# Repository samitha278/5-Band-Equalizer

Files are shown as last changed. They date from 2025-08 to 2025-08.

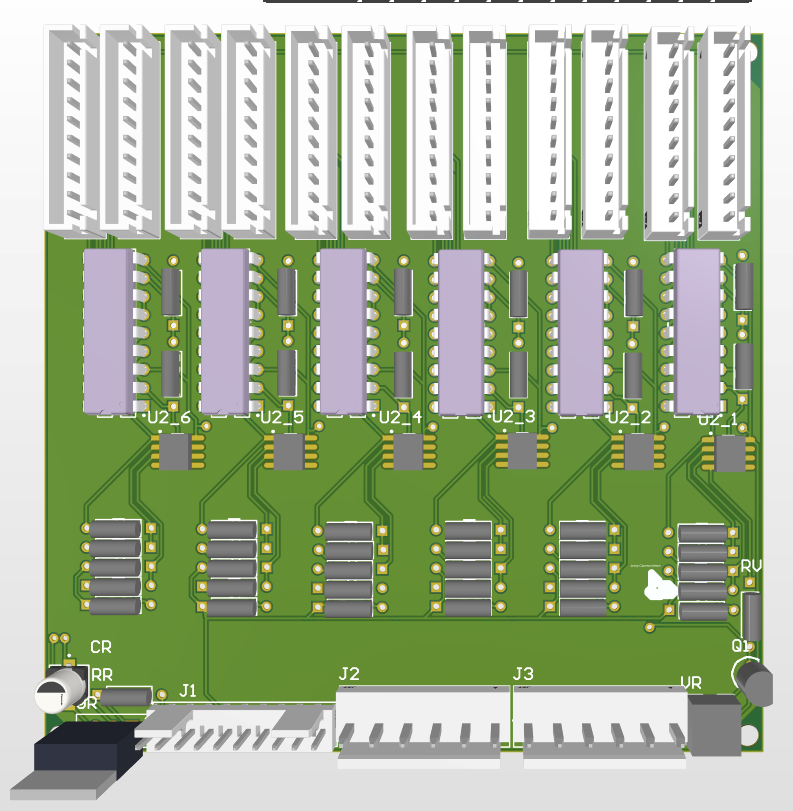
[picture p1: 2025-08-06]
Images/Design and Schematics/display.png

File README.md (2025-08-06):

# 🎚️ 5-Band Analog Audio Equalizer - Hertz Labs

A robust, fully analog 5-band audio equalizer designed and built by undergraduate students of the Department of Electronic and Telecommunication Engineering, University of Moratuwa. The project features selective gain control across five standard audio frequency bands, with a real-time LED bar display for audio levels — all using only fundamental analog components like op-amps, resistors, capacitors, and transistors.

> 📡 Designed for: EN2091 Laboratory Practice and Projects  
> 🧪 Built by: Team Hertz Labs  
> 🎓 University of Moratuwa

---

## 📷 Project Overview

This 5-band equalizer allows users to independently adjust the gain across the following audio frequency bands:

- **20 Hz – 300 Hz** (Sub-bass)
- **300 Hz – 1 kHz** (Bass/Mid)
- **1 kHz – 4 kHz** (Midrange)
- **4 kHz – 10 kHz** (Upper midrange)
- **10 kHz – 20 kHz** (Treble)

The design ensures minimal distortion when idle, accurate band separation, and robust gain control without digital processing — preserving the integrity of the original analog signal.

---

## 🧩 System Architecture

The system is divided into two main blocks:

### 1. 🎛️ Filter & Control Section
- **Input/Buffer Stage:** Inverting amplifier with a gain of -2 and DC shift to mid-voltage.
- **Filter Bank:** Five fourth-order bandpass filters, each built using two cascaded Sallen-Key second-order filters.
- **Adder Stage:** Inverting summing amplifier that combines the filtered signals, each weighted by a volume potentiometer.
- **Mid-Voltage Generator:** Provides a virtual ground reference for single-supply operation.

### 2. 💡 Display Section
- **Differential Amplifiers:** Monitor current flow to the adder circuit without affecting audio fidelity.
- **LED Display Driver:** LM3914 IC used to drive 10-segment LED bar graphs for each frequency band.

---

## 🧠 Key Design Choices

- **Single-Supply Design:** Operates at 18V with mid-voltage reference, avoiding complex dual supply requirements.
- **High-Order Filters:** Fourth-order filtering for each band ensures steep roll-off and minimal overlap.
- **Current-Limiting Resistors:** Prevents saturation at the adder stage and ensures smooth audio performance.
- **Component Compactness:** Utilized SMD op-amps (TL072) for filters and through-hole components where needed for durability and signal integrity.

---

## 📐 Hardware and PCB

- **Design Software:** Altium Designer (2-layer PCB)
- **Main PCB Size:** 100 mm × 84 mm
- **Display PCB Size:** 100 mm × 100 mm
- **Enclosure:** Custom-designed with SolidWorks. PLA+ 3D printed main body + laser-cut plywood front panel.
- **Inputs/Outputs:** 3.5 mm audio jacks and barrel jack for power input.

---

## 🔬 Simulation & Testing

- **Simulation Software:** LTSpice
- **Verification:** Individual filter responses and system-level flat gain tested in simulation.
- **Prototyping:** Breadboard implementation before final PCB.
- **Final Testing:** Oscilloscope and audio output testing verified each band’s control and system integrity.

---

## 🛠️ Components Used

| Component | Description |
|---|---|
| TL072 Op-Amp | Low noise, low distortion, wide bandwidth — ideal for audio applications.  |
| LM3914 | Bar graph LED driver with linear scale, built-in reference voltage. |
| Potentiometers | Sliding potentiometers used for precise gain control of each band. |
| Passive Parts  | Standard 0.25W resistors, film capacitors selected for precision and stability. |

---

## 🚧 Future Improvements

- 🔋 **Custom Power Supply**: Develop an in-house 18V power supply for standalone operation.
- 💡 **Display Enhancement**: Refine LED driver circuit for more accurate real-time response.
- 🔊 **More Bands**: Extend to a 7-band or 10-band equalizer for finer audio tuning.

---

## 👥 Team Members

-Jayakody J.A.K
-Pelagewatta H.P
-Jayarathne H.A.C.N
-Bandara M.A.G.S

---

## 🔗 References

- [LM3914 Datasheet](https://www.ti.com/lit/ds/symlink/lm3914.pdf)
- [Sallen-Key Filter Design Guide - TI](https://www.ti.com/lit/pdf/sloa096)
- [Medium Blog Inspiration](https://medium.com/@vgr0876/5-band-audio-equalizer-8df9b991d8ea)

---

## 📂 Repository Structure

```bash
5-Band-Equalizer-HertzLabs/
├── Schematics/           # LTSpice and Altium design files
├── PCB_Design/           # PCB layout files (Main + Display)
├── Enclosure/            # SolidWorks and Laser-cut designs
├── Media/                # Photos and demo videos
├── Report/               # Final PDF report and documentation
└── README.md             # This file

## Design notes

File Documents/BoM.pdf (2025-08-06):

## Bill of Materials

Component | Quantity | Unit Price (Rs) | Price (Rs)
TL072CP OpAmp SMD | 12 | 80 | 960
LM3914 | 6 | 100 | 600
PCBs | 1 | 6500 | 6500
Enclosure | 1 | 5400 | 5400
Resistor Cards | 2 | 380 | 760
Capacitors | | | 500
Sliding Potentiometer | 6 | 240 | 1440
Barrel jack | 1 | 45 | 45
6.5mm Audio Connector | 2 | 270 | 540
Switch | 1 | 30 | 30
LED Bar graph | 6 | 140 | 840
| | Total | 17615

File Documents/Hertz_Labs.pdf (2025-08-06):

5 Band Equalizer | Hertz Labs
EN2091

# Laboratory Practice and Projects

# 5-Band Equalizer

# Team – Hertz Labs

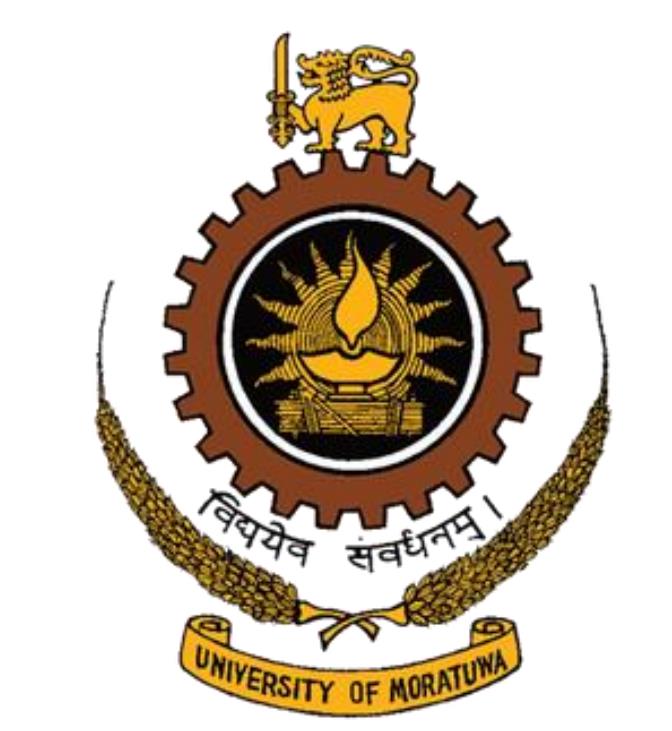
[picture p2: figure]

Electronics and Telecommunications Department,

## University of Moratuwa

Members
220247J | Jayakody J.A.K
220455U | Pelagewatta H.P
220252U | Jayarathne H.A.C.N
220064U | Bandara M.A.G.S.

## Abstract

This report contains an overview of the design of a 5-band equalizer based on basic electronic components such as OP AMPs, resistors, capacitors and transistors. The Equalizer is designed to work for an input voltage range of 18-30V and provides highly selective individual band gain adjustment with minimal distortion to the other band responses. The equalizer at rest position

introduces minimal distortion to the response.

### The fundamental building blocks of the equipment and the core concepts related to it, simulation methodologies, testing methods, components

selection, PCB design and enclosure design is briefly discussed in the report.

### The final output and audio testing has given very pleasing results with accurate gain adjustments both in audio outputs and oscilloscope measurements

proving the effectiveness of the design.

## Content

Introduction | 4
Functionality | 4
System Architecture, Major Design Decisions and Fulfilling the Given Requirements | 4
Component Selection | 9
PCB Design | 10
Enclosure Design | 11
Software Simulation | 12
Practical Implementation and Testing | 12
Conclusion | 13
Future Work | 13
Individual Contribution | 13

### References

13

## Introduction

### An audio equalizer can adjust the output of different frequency bands individually based on a given audio signal. The project was centred around making an equalizer with gain control of 5 individual bands using only basic analog electronic equipment. The audio levels of each band must be

graphically indicated using a sound level indicator.

## Functionality

The input/ buffer receives the audio signals and add a DC shift to bring the signal to the mid voltage.5 band pass filters tuned to the assigned bands decompose the input audio signals. These filtered signals are added by an adder circuit and the proportions of adding are controlled by volume controllers. (potentiometers). The Output is driven by the same Adder output.

The frequency ranges of each band.

– 20-300 Hz
– 300 - 1 kHz
– 1kHz - 4 kHz
– 4kHz - 10kHz
– 10kHz - 20kHz

## System Architecture, Major Design Decisions and Fulfilling the Given Requirements

The design decision was taken to go for a single supply design since we are expecting to rely on a external power supply with normally provides a single supply. (External dual power supplies are rare in market)

So, all the stages of the circuit was designed to work according to it.

### Block Diagram

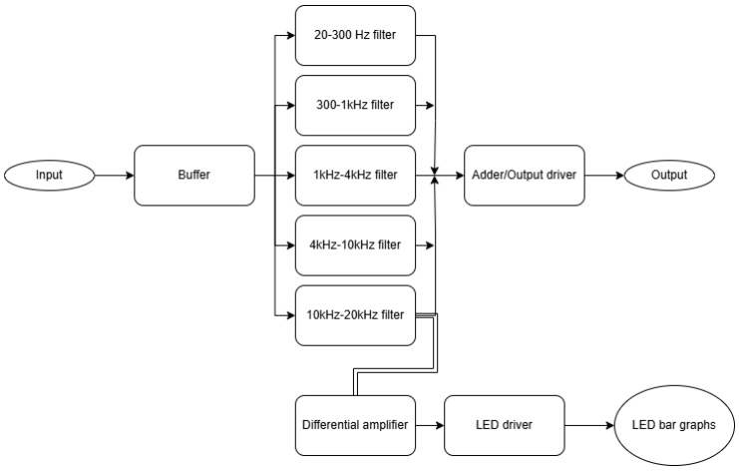
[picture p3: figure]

Figure 1-Functional block Diagram

The system is divided into 2 major parts.

1. Filter section
2. Display control section

Filter section

Consists of 3 stages
1. Input/Buffer stage – A inverting amplifier of gain -2
2. Filter stage - 2 second order Sallen key multiple feedback bandpass filters cascaded to get a fourth order filter for each band. 5 such filters are present.
3. Adder/Output stage – Volume controllers are used to control the contribution from each band and the current is passed through the adder circuit to generate the output voltage.

Additionally, it has a mid-voltage generator section- Mid voltage is taken to act as the virtual ground to simplify the design the single supply op amp circuits.

Display Section

Consists of 2 stages

1. Differential amplifier stage – Sense the current levels of each filter stage flowing to the adder section without introducing distortion to the bands
2. LED driver stage – Drive a 10 LED bar graph display proportional to the voltage output of the first stage.

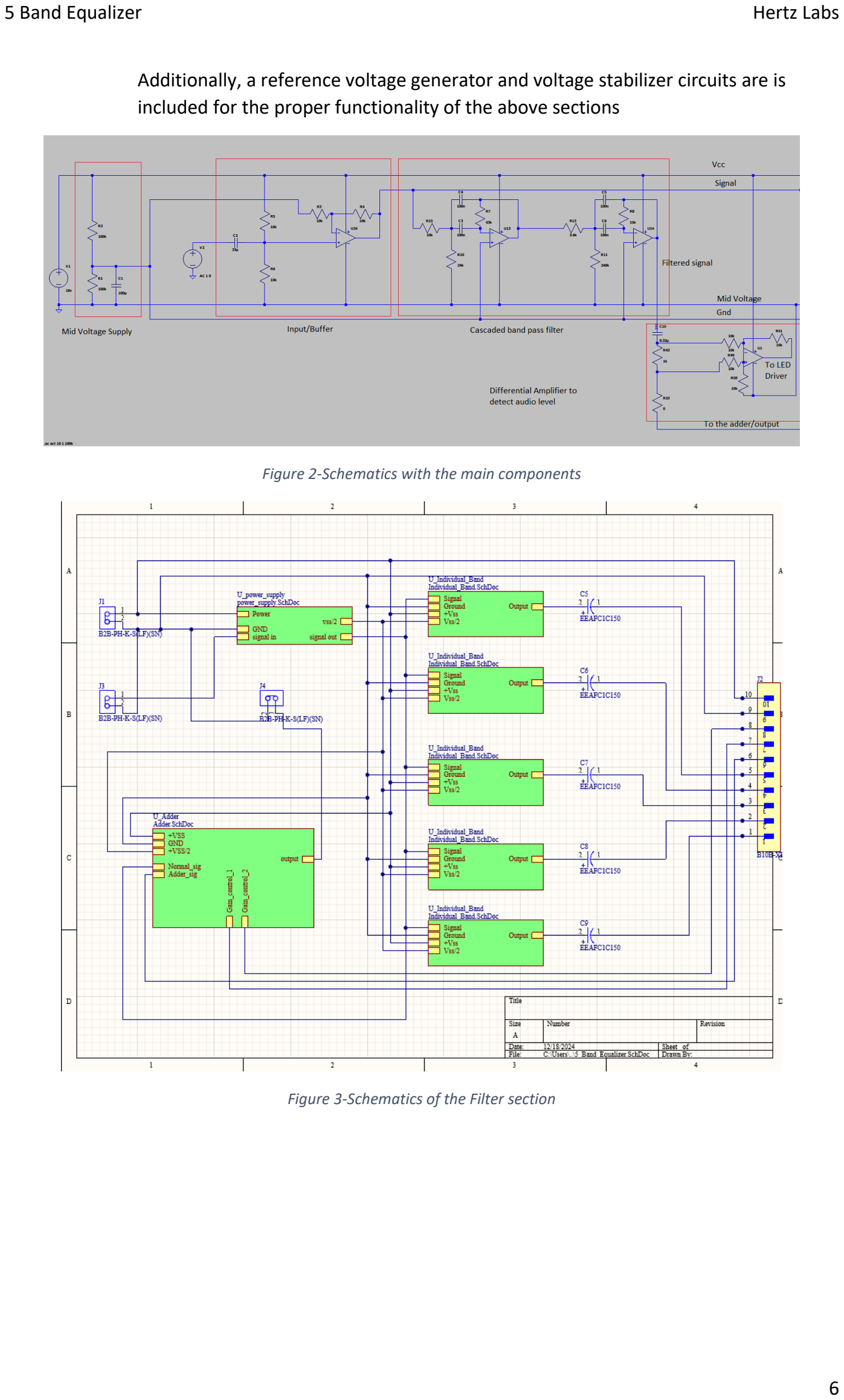
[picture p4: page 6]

Additionally, a reference voltage generator and voltage stabilizer circuits are is included for the proper functionality of the above sections

Figure 2-Schematics with the main components

Figure 3-Schematics of the Filter section

### Use of analog electronics for implementation (transistors and operational amplifiers)

- Input/stage

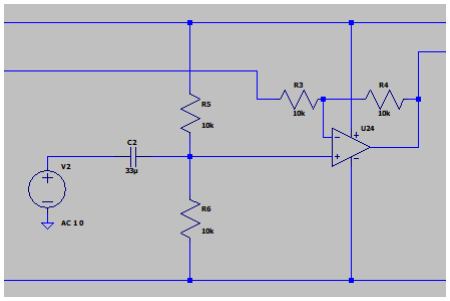
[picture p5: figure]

The input stage is an inverting amplifier constructed using a single OP amp and resistors. This stage introduces a DC shift to the signal and give a gain of -2. The gain is introduced to manipulate the signals with minimal
introduction of noise from the filters and background noise. The input stage has an almost flat frequency response (High pass)
- Filters

The filter stages is
constructed by cascading 2 Sallen key multiple feedback band pass filters to get a fourth order filter. This is used to give a steep roll off which gives a good selectivity. Also, the filters are tuned such that the first filter is handling the first portion of the filter while the second filter handles the
second portion of the

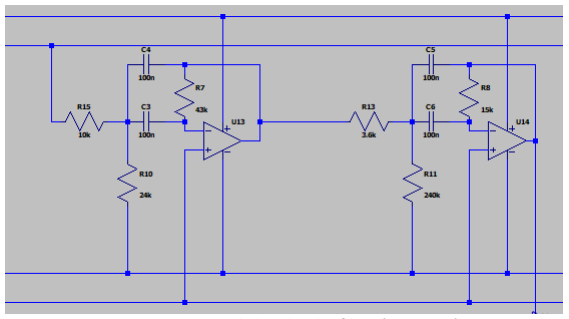
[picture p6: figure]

band. This ensure that the pass band has a flat mid frequency gain.

Adder stage

Adder is an OP amp based single supply adder circuit which combines the signals from the filters proportional to the resistance introduced by the volume controllers between the filter and the adder. The adder circuit is also inverting the signal which ultimately converts the signal to the original phase.

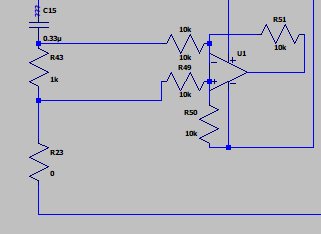
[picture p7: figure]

Differential amplifier

The differential amplifier is connected to the saturation control resistor. The differential amplifier senses the voltage difference between the resistor which is proportional to the current flow through it. Then it outputs the output which is in the range of the input

Figure 4-Input Stage

Figure 5- cascaded 2nd order filters(4th order)

signals to the display driver. Due to the high input impedance of the differential input this does not introduce any distortions to the signal.

Display driver.

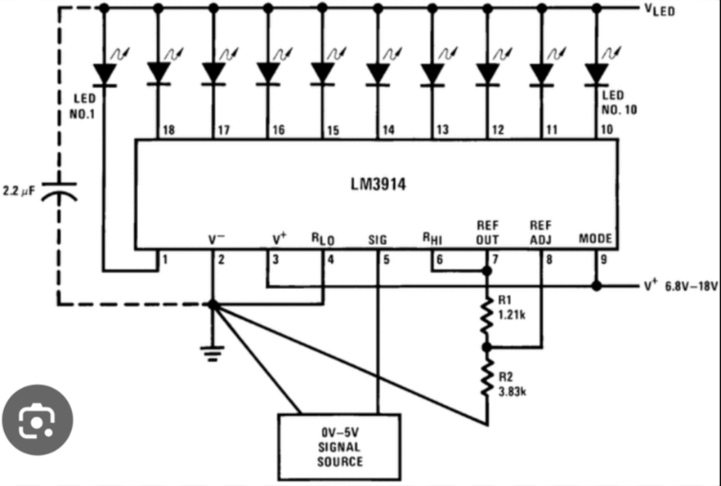
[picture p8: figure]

We have used a 10 segment display driver(LM3914) which switches the LEDs proportional to the input voltage ranging from 0-5V

Capable of adjusting the gain individually across 5 frequency bands.

As described previously this requirement is achieved by filtering the signal into several bands and then controlling the contribution of each band to the final output individually.
Mechanisms to avoid signal saturation.

A current control resistor is introduced between the filters and the volume controllers which limits the current to the adder stage. This ensures that the final output stage will not be saturated by any means. The value of this resistor is calculated such that for any position of the volume controller the input current to the adder circuit is controlled and the output is not saturated. Furthermore, all the filters are designed to handle input voltage variations way beyond the normal audio line voltages. This ensures that for any normal audio signal, the input/buffer stage and the filter stages will not saturate. The supply voltage of the system was selected to be 18V which was decided on the fact that 12V supply voltage is the minimum voltage needed to avoid saturation of the signals.

## Component Selection

Op amp selection – We decided to use TL 072 OP amp for all the circuits in the system.

### The TL072 operational amplifier (op-amp) is often considered good for audio applications due to several characteristics that make it well-suited for this purpose:

### 1. Low Noise: The TL072 has low noise characteristics, which are crucial in audio applications where signal fidelity is important. Low noise helps in maintaining the

quality of the audio signal being amplified.

### 2. High Input Impedance: The TL072 has a high input impedance, which means it won't load down the preceding stages in an audio circuit. This is important to prevent signal

loss and distortion.

### 3. Wide Bandwidth: The TL072 has a wide bandwidth, making it suitable for audio

applications where a broad frequency range needs to be amplified without distortion.

### 4. Low Distortion: The TL072 has low distortion characteristics, which are essential for

maintaining the fidelity of audio signals as they pass through the amplifiers and filters.

### 5. Dual Op-Amp Configuration: The TL072 is a dual op-amp in a single package, which is

convenient for filter stages since each stage needs 2 OP amps.

### 6. Ease of Use and supply: It is a commonly used and well-documented op-amp, making it easier for designers to find information, application notes, and example circuits for

audio applications.

### We used SMD Op amps for all the filters and the adder to increase the compactness of the PCB and we used a Through hole Op amp since this has to introduce a DC sift for the signal

Resistors - All the resistors were selected based on the calculations needed for filters and the other circuits. All the resistors are 0.25W resistors since all the circuits deal with signals. The resistor selection for the op amp circuits were done such that they fall in the range of 1kohm to 100kohm to avoid injection of thermal noises to the signals.

### Display driver – LM3914

### 1. Bar/Dot Display Modes: The LM3914 can operate in either bar mode or dot mode, allowing flexibility in how the display is presented based on the application requirements. We decided to use the bar mode 2. Linear Voltage Scale: The LM3914 has a linear voltage scale, which is useful for

applications where a linear representation of levels or quantities is needed, such as audio level indicators which is exactly our requirement.

### 3. Wide Voltage Range: The LM3914 can operate over a wide range of supply voltages, making it versatile and suitable for various power supply configurations. This makes the use of a separate supply circuit to the display

drivers unnecessary.

### 4. Internal Voltage Reference: The LM3914 includes an internal voltage reference, simplifying the design by eliminating the need for an external voltage reference. This gives our device the ability to work on defferent supply voltages

while still maintaining a fixed scale.

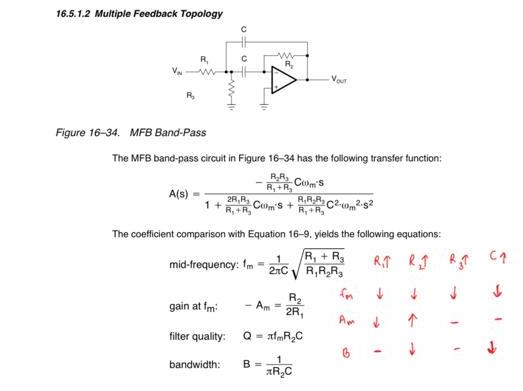
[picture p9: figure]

## PCB Design

The printed circuit board (PCB) for the 5-Band Audio Equalizer was designed using Altium Designer with 100 mm × 84 mm dimensions. The design utilizes a two-layer PCB architecture to accommodate the circuit complexity while maintaining an organized layout.

The PCB was fabricated in China and shipped to Sri Lanka for assembly and testing. The trace width for signal lines is 0.254 mm, ensuring optimal current flow and signal integrity. The drill hole diameter for PCB mounting is 3 mm, providing adequate mechanical support and alignment.

The placement of components was carried out systematically to ensure clarity and ease of understanding. Each frequency band is distinctly organized, enabling intuitive identification and streamlined troubleshooting. This structured layout enhances both the functionality and usability of the PCB, facilitating efficient assembly and testing processes.

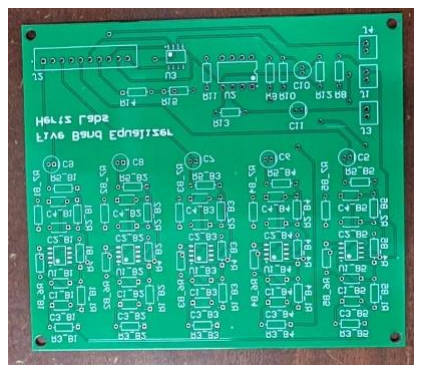
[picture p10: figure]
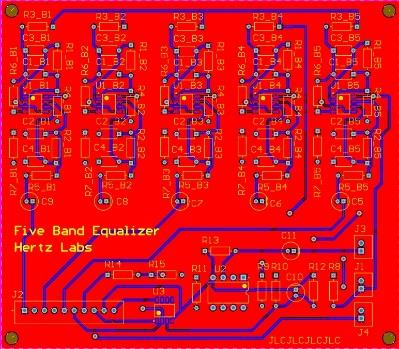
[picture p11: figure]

In addition to the main PCB, a separate display PCB was designed for the 5-Band Audio Equalizer using Altium Designer. This PCB measures 100 mm × 100 mm and features a two-layer design to support the display components.

The trace width for signal lines is 0.254mm, ensuring reliable electrical connections, while the drill hole diameter is maintained at 3 mm for PCB mounting.

The components on the display PCB, such as the LED bar graph displays and sliding potentiometers, are strategically organized to align precisely with the corresponding features of the enclosure. This alignment ensures seamless integration of the display interface with the enclosure design, resulting in a user-friendly and visually coherent system layout.

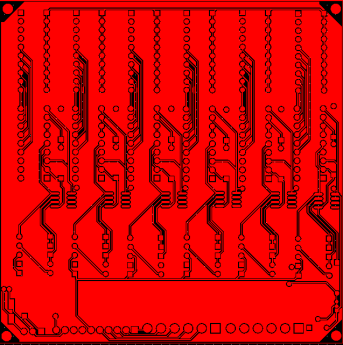
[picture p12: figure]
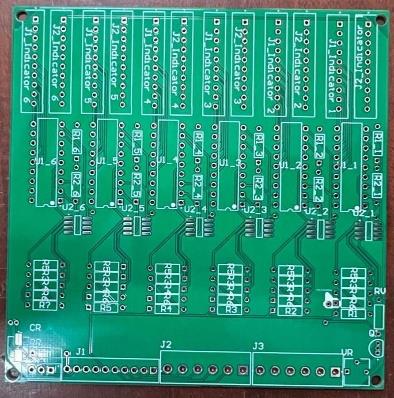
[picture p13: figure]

## Enclosure Design

The enclosure for the 5-Band Audio Equalizer was designed using SolidWorks and consists of three distinct components: the Main Container, the Lid, and the Face. The enclosure dimensions are 150 mm × 142 mm, ensuring compactness while accommodating all required components.

- The Main Container and Lid were fabricated using 3D printing technology with PLA+ filament for enhanced durability and precision.
- The Face of the enclosure was laser-cut from a plywood sheet, providing a robust and aesthetically appealing front panel.

The enclosure integrates the following components:

- 5 sliding potentiometers for adjustable gain control.
- 5 LED bar graph displays for real-time visual feedback.
- 1 switch for system control.
- 2 audio jack connectors (65 mm) for audio input and output.
- 1 barrel jack connector for power supply.

The main PCB is mounted on the inner face of the lid, while the display PCB is securely mounted inside the Main Container. Both PCBs are positioned in a face-to-face configuration, simplifying wire connections and minimizing signal interference, ensuring efficient assembly and reliable operation.

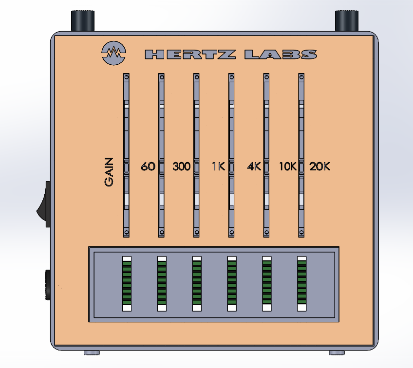
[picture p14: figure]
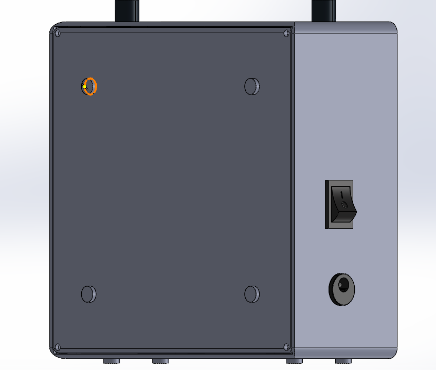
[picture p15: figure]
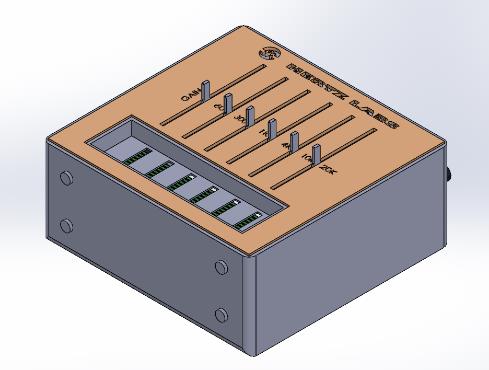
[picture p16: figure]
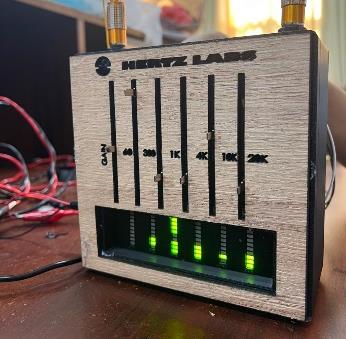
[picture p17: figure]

## Software Simulation

The circuit was simulated using LTSpice software to verify its performance and optimize component values. The output response for each frequency band was plotted, demonstrating accurate results with a well-defined roll-off at the frequency edges. Based on the simulation results, appropriate resistor and capacitor values were carefully selected to ensure precise frequency band separation and optimal performance of the 5-Band Audio Equalizer.

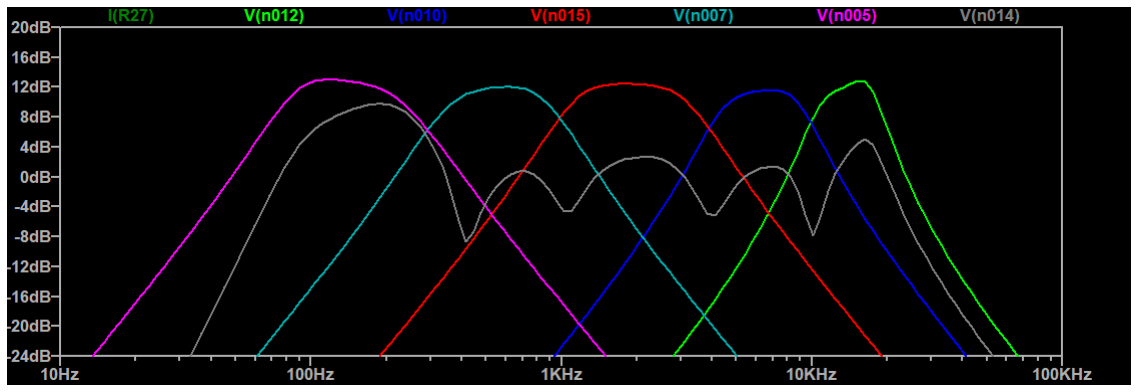
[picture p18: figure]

This image shows the response of each individual filter and the overall response of the equalizer when the system is at neutral position. Contribution of each band to the output can be adjusted by varying the potentiometers

## Practical Implementation and Testing

The circuit was implemented on a breadboard following the simulation for practical verification. The resistor values were fine-tuned through experimentation to optimize the output response. This step ensured the circuit achieved the most accurate and reliable performance, aligning closely with the simulated results.

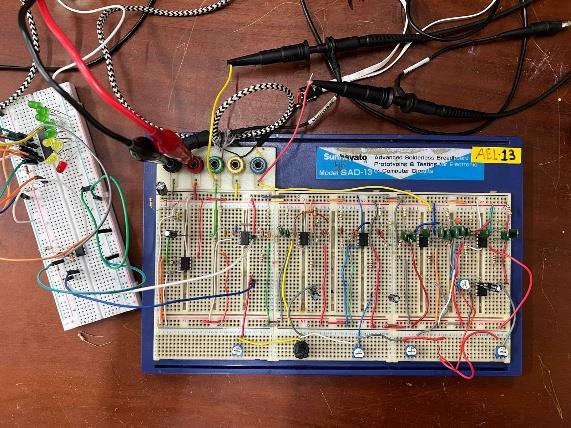
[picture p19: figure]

After optimizing the circuit on the breadboard, the PCB layout was designed using Altium software. The PCB was fabricated and tested to ensure proper functionality. All components were carefully soldered onto the PCB, and the assemblies were integrated into the enclosure. The final product was subjected to comprehensive testing, where it successfully met the expected performance criteria, validating both the design and implementation processes.

## Conclusion

In conclusion the component selection and the circuit design is very robust and the testing proved that the system has met all the design requirements. The use of analog circuits for audio applications can preserve the quality of th audio signals and also at the same time cost effective for small scale audio signal processing. The 5 band analog equalizer can be further extended to handle multiple bands in the audio frequencies.

## Future Work

1. Custom Power Supply Development
Currently, the device is powered using the laboratory signal generator to supply the required voltage. As part of future improvements, a dedicated in-house power supply will be designed and implemented to provide a stable 18V power source, ensuring portability and independence from external equipment.
2. Optimization of LED Bar Graph Display
The LED bar graph displays did not perform as expected, with the levels not accurately reflecting changes in the signal output. Further testing and analysis of the display circuit are necessary to identify the discrepancies. An improved design will be implemented to achieve precise and reliable visual output for the display.

## Individual Contribution

220247J | Jayakody J.A.K | Overall circuit design, Display PCB Design, Simulations, Circuit Building, Breadboard Implementation, Documentation.
220455U | Pelagewatta H.P | Main PCB Design, PCB Testing, Soldering
220252U | Jayarathne H.A.C.N | Enclosure Design, Assembling, Filter Calculations and Testing, Documentation
220064U | Bandara M.A.G.S. | Filter Calculation, Documentation

## References

https://www.ti.com/lit/ds/symlink/lm3914.pdf

https://www.ti.com/lit/pdf/sloa096

https://medium.com/@vgr0876/5-band-audio-equalizer-8df9b991d8ea

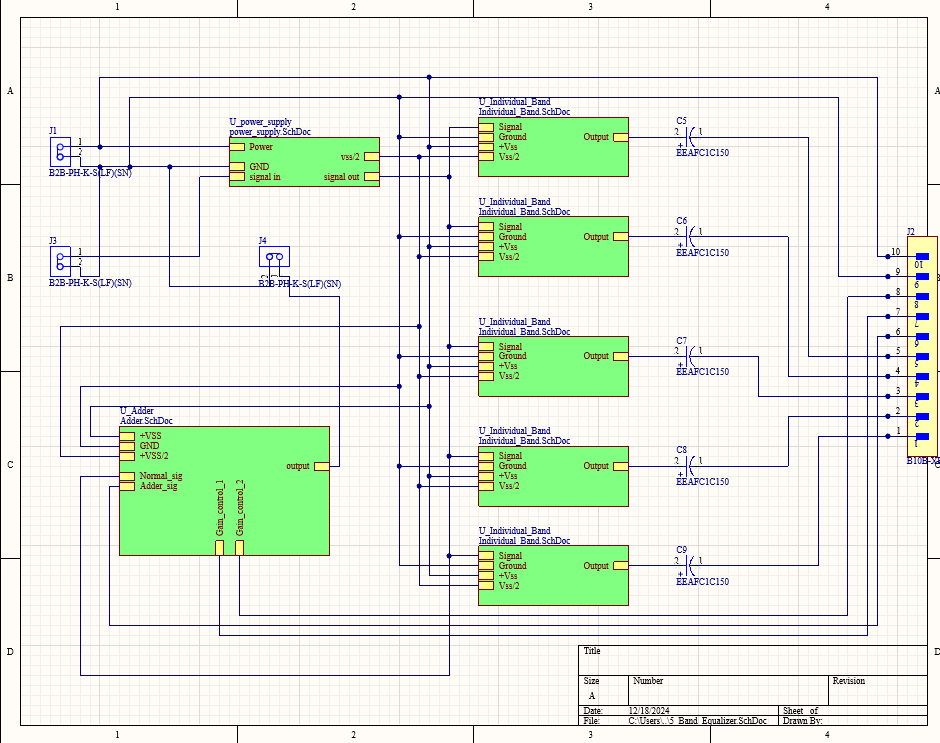
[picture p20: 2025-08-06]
Images/Design and Schematics/Schematics.png

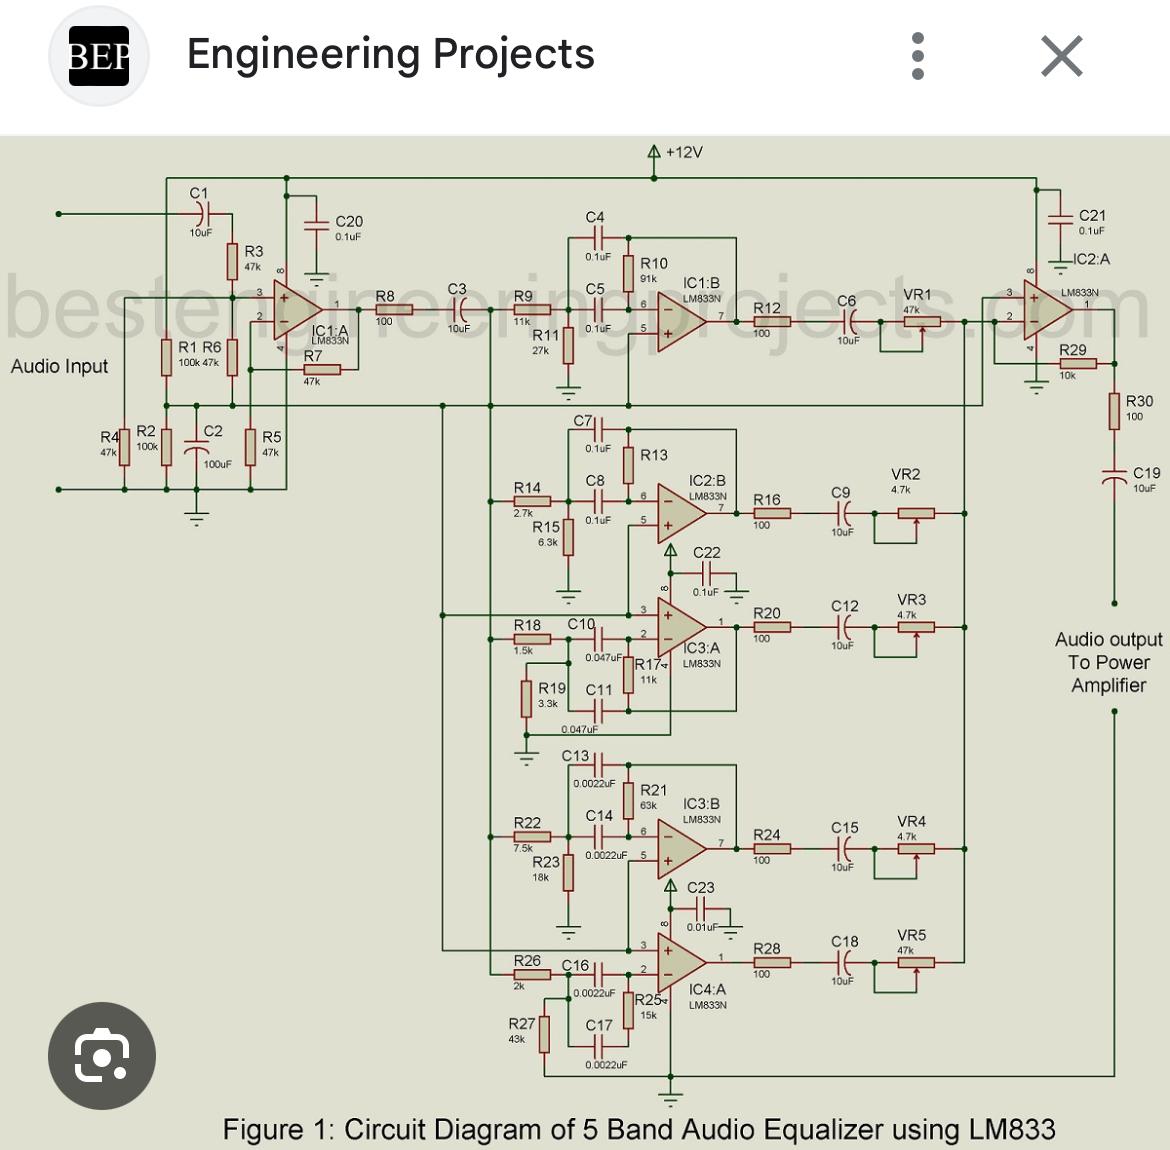
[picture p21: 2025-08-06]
Images/Design and Schematics/reference.jpg

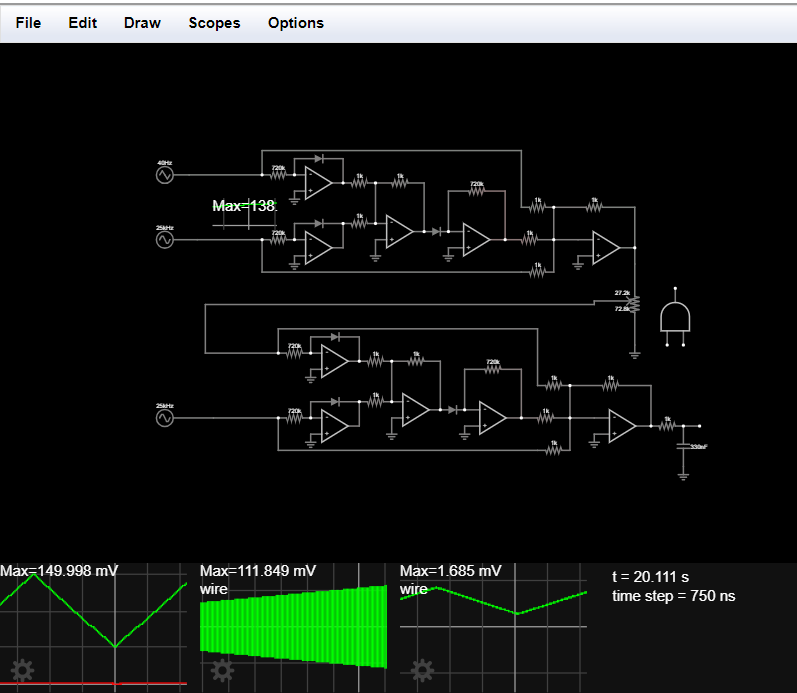
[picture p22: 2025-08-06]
Images/Design and Schematics/Screenshot 2024-08-25 143552.png

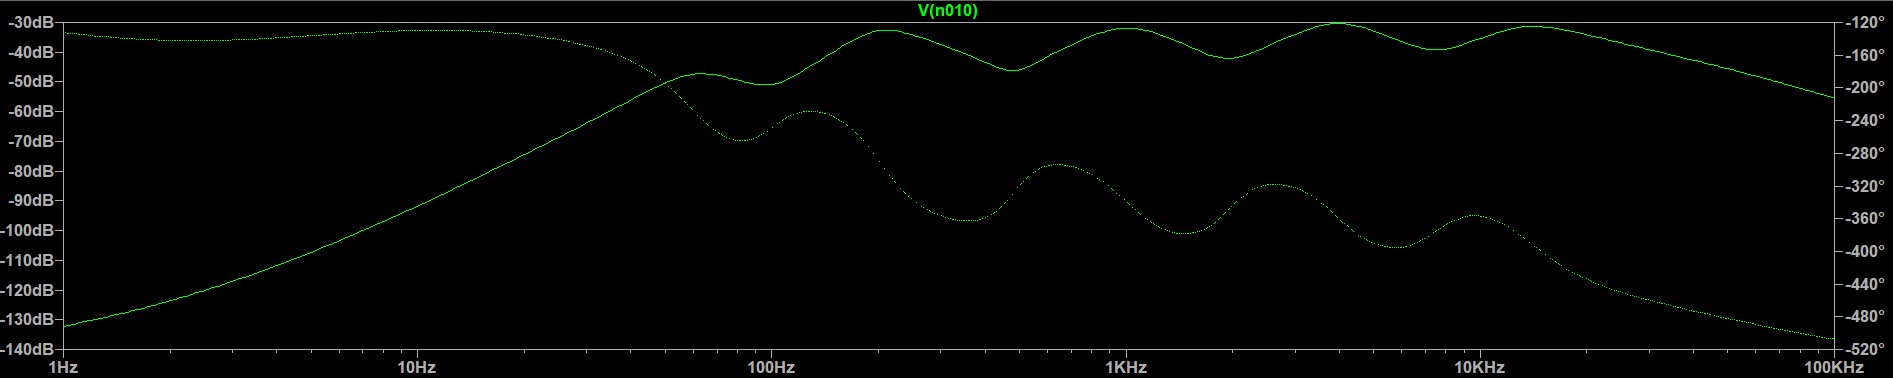
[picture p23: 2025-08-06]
Images/Design and Schematics/response_2.png

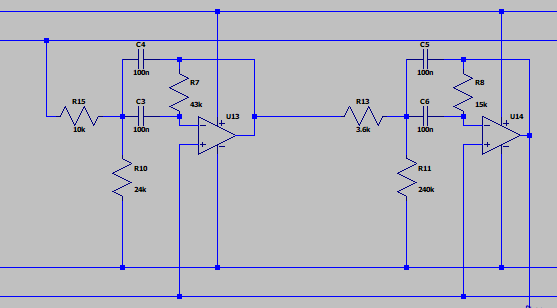
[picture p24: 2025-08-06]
Images/Design and Schematics/filter.png

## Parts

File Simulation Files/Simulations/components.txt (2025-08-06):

lm 358 - 6
10k
47k
180k
68k
15k
1.5k
3.3k
2.7k
12k
680
2.2k
470k
3.3k

6.8nF
68 nf
12k

10nf
100nf
0.047k
33nm
15um
1nf

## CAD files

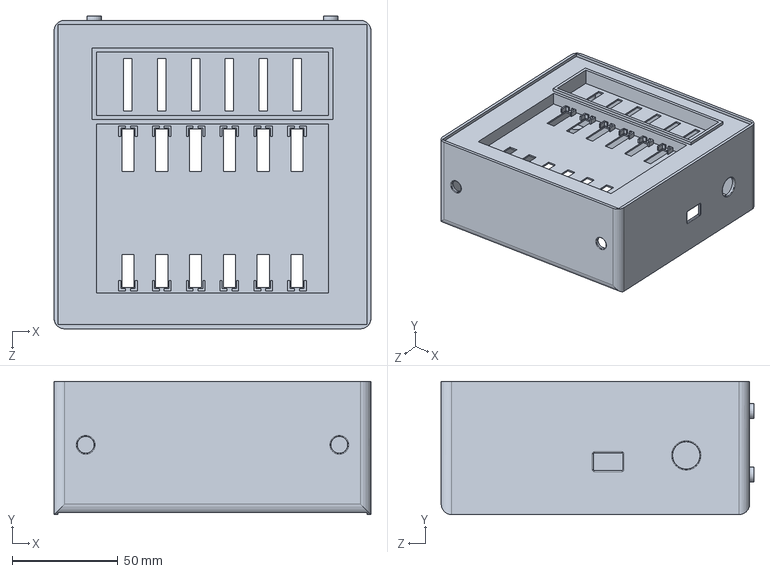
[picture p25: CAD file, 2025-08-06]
Enclosure/Enclosure.SLDPRT
150.0 x 63.0 x 148.0 mm

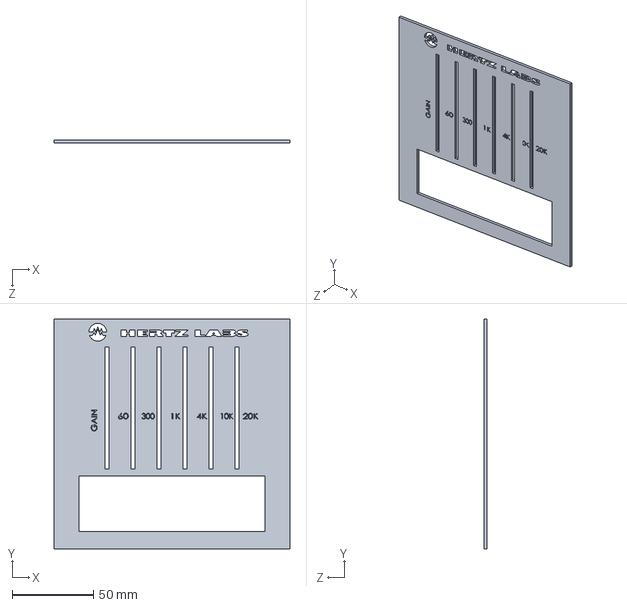
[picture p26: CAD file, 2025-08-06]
Enclosure/Wooden_Face.SLDPRT
145.5 x 141.5 x 2.00 mm

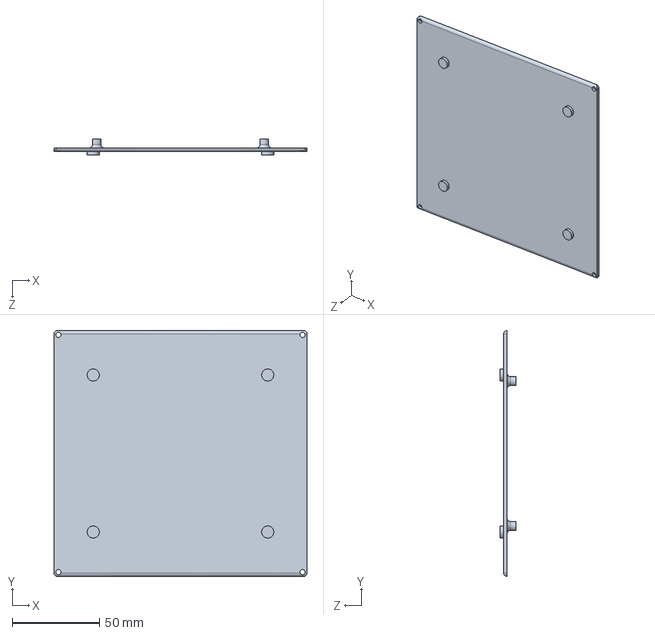
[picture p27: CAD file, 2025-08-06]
Enclosure/Lid.SLDPRT
145.0 x 141.0 x 9.00 mm
